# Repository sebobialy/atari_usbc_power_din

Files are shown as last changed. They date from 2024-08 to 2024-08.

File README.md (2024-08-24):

# Introduction

This is a simple power DIN connector USB-C replacement for Atari 8-bit computers, with PowerDelivery capability.

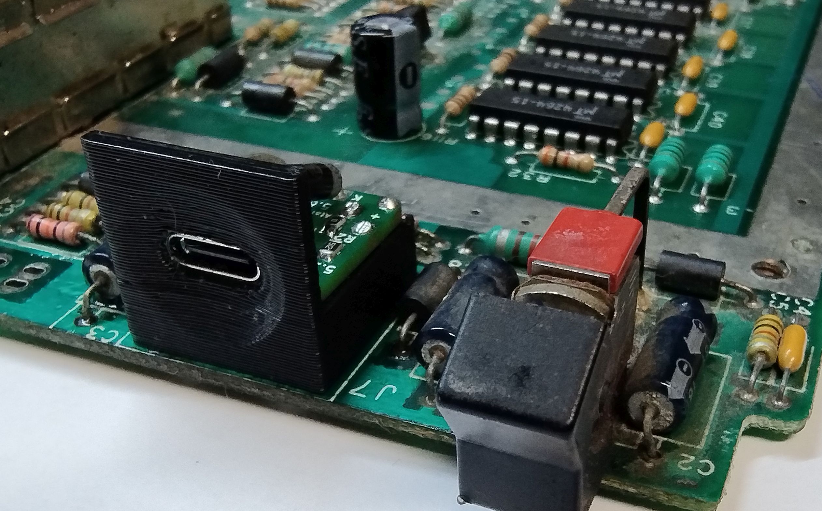
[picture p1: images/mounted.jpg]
mounted

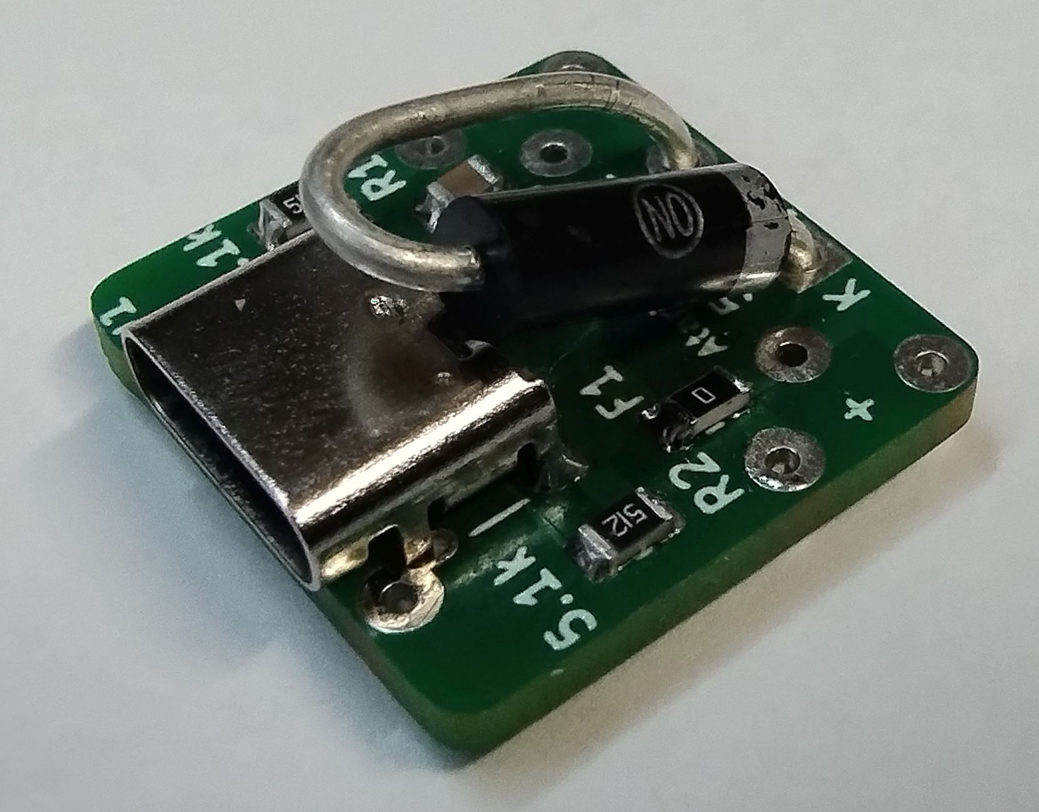
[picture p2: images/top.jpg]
top

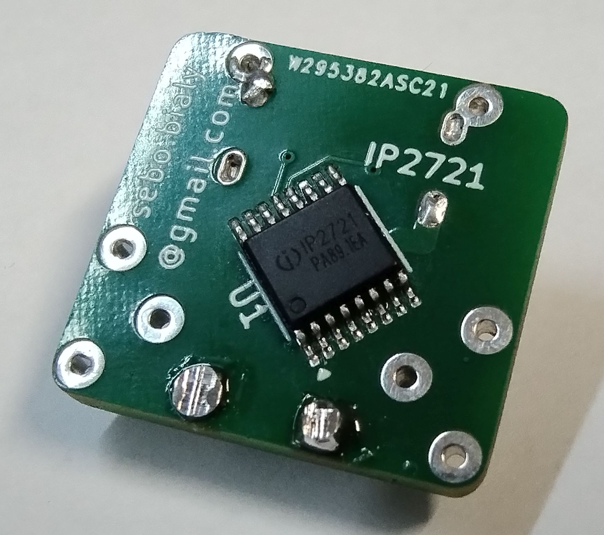
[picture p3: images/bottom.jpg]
bottom

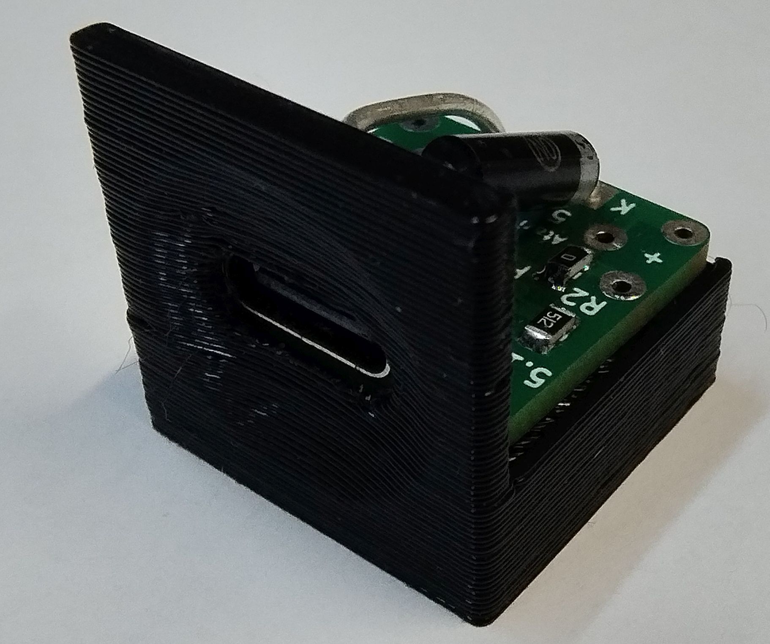
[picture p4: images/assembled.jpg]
assembled


# Options

## Simple

* PCB
* USB-C connector
* Jumper over fuse

This configuration will work with dumb chargers that do not care about PD. Should work also with USB-C<>USB-A cables.

## Advanced

* PCB
* USB-C connector
* IP2721
* 5.1kOhm resistors
* Jumper over fuse

This configuration will work with all PowerDelivery chargers, via USB-C<>UAB-C cables. Should work with power banks, phone chargers, laptop chargers, etc.

## Ultimate

* PCB
* USB-C connector
* IP2721
* 5.1kOhm resistors
* 10nF capacitor
* 5.6V zener diode around 5W
* Polyfuse 1-2A.

This configuration will work with all chargers and additionally protect your hardware from reversed polarity or overvoltage, just in case.

# PCB

PCB was designed using KiCAD. All components are 0805 in size.

# Stand

To properly mount this DIN replacement, you need to print a small stand, using any 3D printer. OpenSCAD file is provided. Please install OpenSCAD, load the design file, press F6, and export STL for printing. You will also need some wires to solder it, trough the stand.

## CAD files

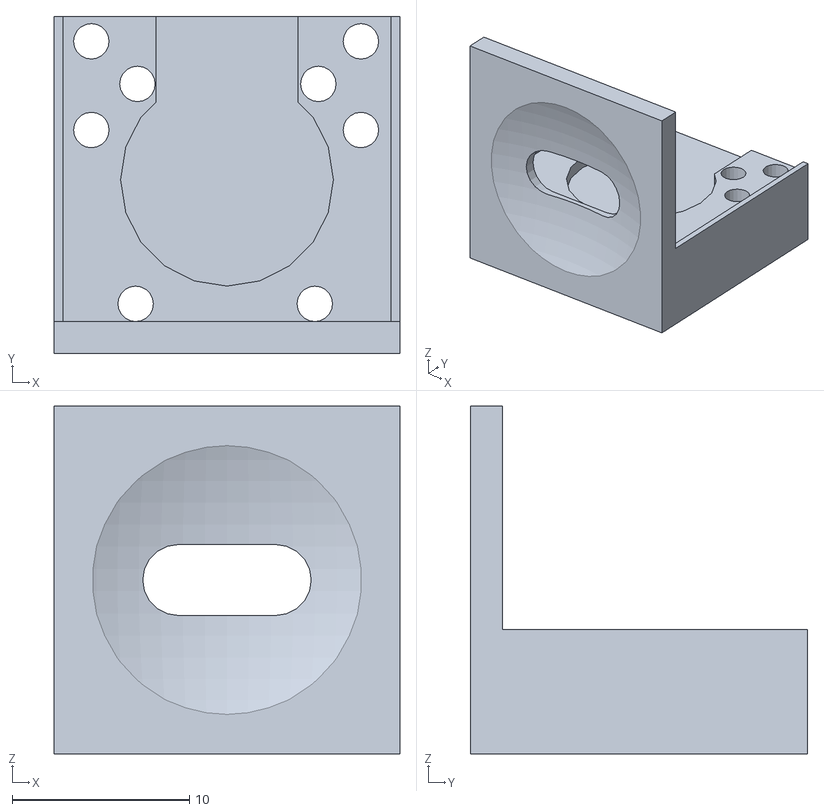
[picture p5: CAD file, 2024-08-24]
production/v1.0/power_din_mount.stl
19.5 x 19.0 x 19.6

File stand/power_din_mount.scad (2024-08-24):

bodyHeight = 19.6;
bodyWidth = 19.5;
bodyDepth = 19;
frontThickness = 1.8;
mountingHoleDiameter=2;

pcbThickness = 1.6;
pcbWidth = 18.5;
pcbDepth = 17.5;

connectorWidth = 9.5;
connectorHeight = 4;

icY = 9.6;
icThickness = 1;
icDiameter = 12;
diodeWidth = 8;

cylinderPrecision=20;
spherePrecision=100;

baseHeight = bodyHeight/2 - pcbThickness/2 - connectorHeight/2;

dentDiameter = 40;
dentThickness = 0.3;

module mountingHoles() {
    xFix = 0.4;
    
    holes = [
     [3.7,1],[13.8,1]
    ,[1.2,10.8] ,[1.2,15.8], [3.8,13.4]
    ,[16.4,10.8],[16.4,15.8],[14,13.4] ];
    xOffset = (bodyWidth - pcbWidth)/2;
    for (i = [ 0 : len(holes) - 1 ]) 
    {
        point=holes[i];
        translate([point[0]+xOffset+xFix,point[1]+frontThickness,0])
        {
            cylinder(d=mountingHoleDiameter,h=bodyHeight, $fn=cylinderPrecision);
        }
    }
}

module bodyBase() {
    difference() {
        cube([bodyWidth, bodyDepth, bodyHeight]);
        translate([0,frontThickness,baseHeight]) { cube([bodyWidth, bodyDepth, bodyHeight]); };
    }
};

module pcb() {
    xOffset = (bodyWidth - pcbWidth)/2;
    yOffset = baseHeight - pcbThickness/2;
    translate([xOffset,frontThickness,yOffset]) { cube([pcbWidth,pcbDepth,pcbThickness]);};
}

module connector() {
    zOffset = baseHeight+pcbThickness/2+connectorHeight/2;// (bodyHeight-pcbThickness)/2;
    translate([bodyWidth/2,frontThickness/2,zOffset]) {
        rotate([90,0,0]) {
            hull() {
                translate([connectorWidth/2 - connectorHeight/2,0,0]) { cylinder(d=connectorHeight,h=frontThickness,$fn=cylinderPrecision,center=true); }
                translate([-(connectorWidth/2 - connectorHeight/2),0,0]) { cylinder(d=connectorHeight,h=frontThickness,$fn=cylinderPrecision,center=true); }
            }
        }
    }
}

module icCutout() {
    translate([bodyWidth/2,bodyHeight/2,baseHeight-icThickness - pcbThickness/2]) {
        cylinder(d=icDiameter,h=icThickness,$fn=cylinderPrecision);
    }
}

module diodeCutout() {
    translate([(bodyWidth - diodeWidth)/2,bodyDepth/2,baseHeight-icThickness - pcbThickness/2]) {
        cube([diodeWidth,bodyDepth/2,icThickness]);
    }
}

module dent() {
    translate([bodyWidth/2, -dentDiameter/2 + frontThickness - dentThickness, bodyHeight/2]) { sphere(d=dentDiameter, $fn=spherePrecision); };
}

difference() {
    bodyBase();
    mountingHoles();
    connector();
    icCutout();
    diodeCutout();
    dent();
    pcb();
}

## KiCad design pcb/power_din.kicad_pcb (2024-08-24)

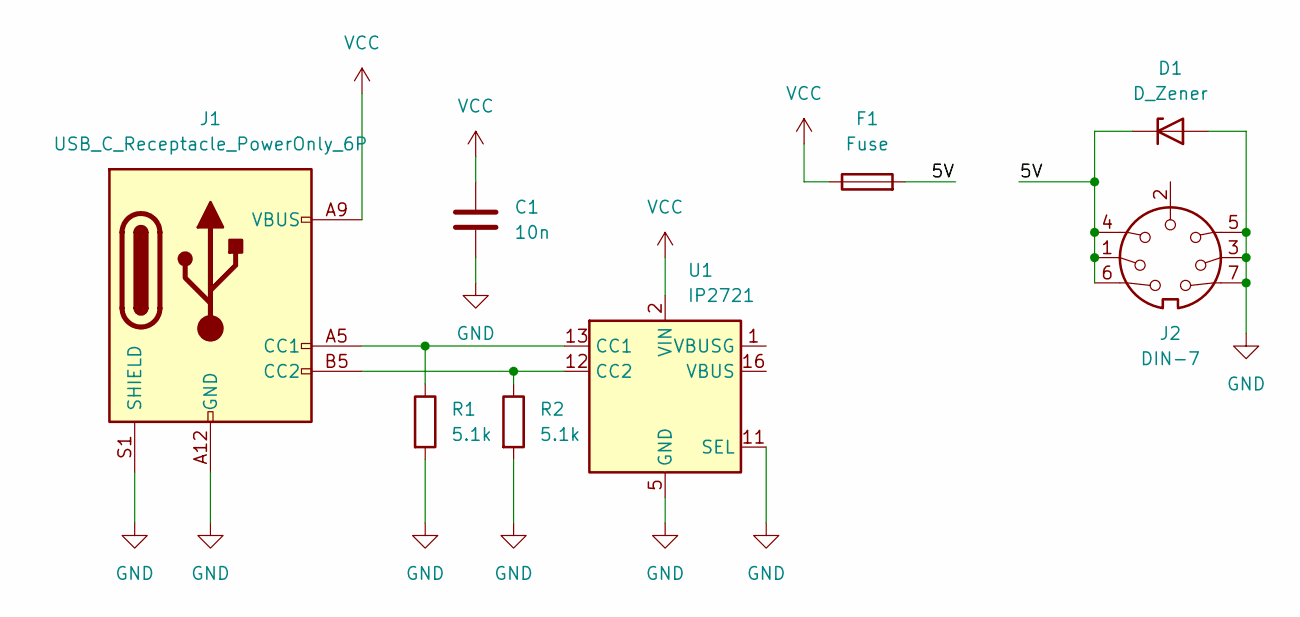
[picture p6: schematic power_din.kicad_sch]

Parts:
C1: 10n; C_0805_2012Metric
D1: D_Zener; D_T-1_P5.08mm_Horizontal
F1: Fuse; Fuse_0805_2012Metric
J1: USB_C_Receptacle_PowerOnly_6P; USB_C_Receptacle_GCT_USB4125-xx-x_6P_TopMnt_Horizontal
J2: DIN-7; din7_fake
R1, R2: 5.1k; R_0805_2012Metric
U1: IP2721; TSSOP-16_4.4x5mm_P0.65mm

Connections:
/5V: D1.1 (K), F1.2, J2.1, J2.4, J2.6
GND: C1.2, D1.2 (A), J1.A12 (GND), J1.B12 (GND), J1.S1 (SHIELD), J2.3, J2.5, J2.7, R1.2, R2.2, U1.5 (GND), U1.11 (SEL)
unnamed: J1.A5 (CC1), R1.1, U1.13 (CC1)
unnamed: J1.B5 (CC2), R2.1, U1.12 (CC2)
VCC: C1.1, F1.1, J1.A9 (VBUS), J1.B9 (VBUS), U1.2 (VIN)

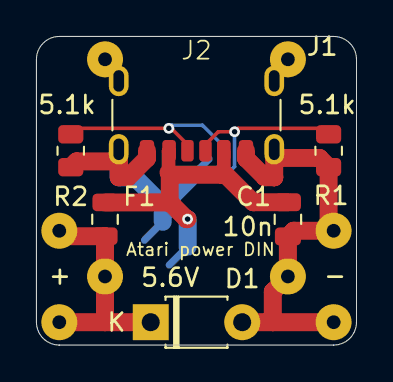
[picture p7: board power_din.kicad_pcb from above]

Board: 2 copper layers, 17.8 x 17.1 mm, 8 parts (1 on the bottom side), 5 nets.
